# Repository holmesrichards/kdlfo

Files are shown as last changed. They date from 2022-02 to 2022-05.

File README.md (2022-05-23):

# Shape variable dual LFO

This is a dual LFO synth module in Kosmo format, based on a [Kassutronics design](https://kassu2000.blogspot.com/2015/10/variable-waveshape-lfo.html). There are three outputs for each LFO. Depending on the shape pot setting these provide ramp, asymmetric triangle, symmetric triangle, or sawtooth waveforms; sine or skewed "sine" waveforms; and narrow, square, or wide pulse waveforms respectively.

Version 1.0 corrects some first run problems. Version 1.0 PCB has not been tested.

## Current draw
32 mA +12 V, 32 mA -12 V

## Photos

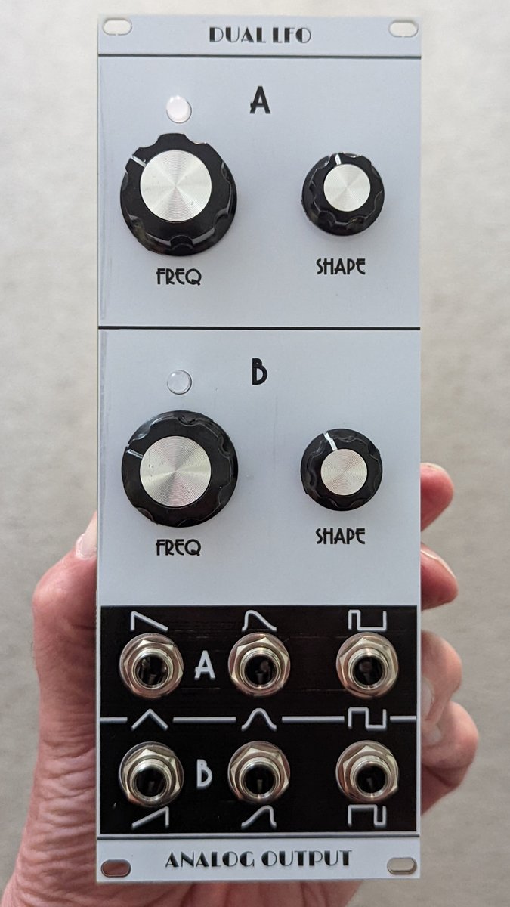
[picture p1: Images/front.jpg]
front


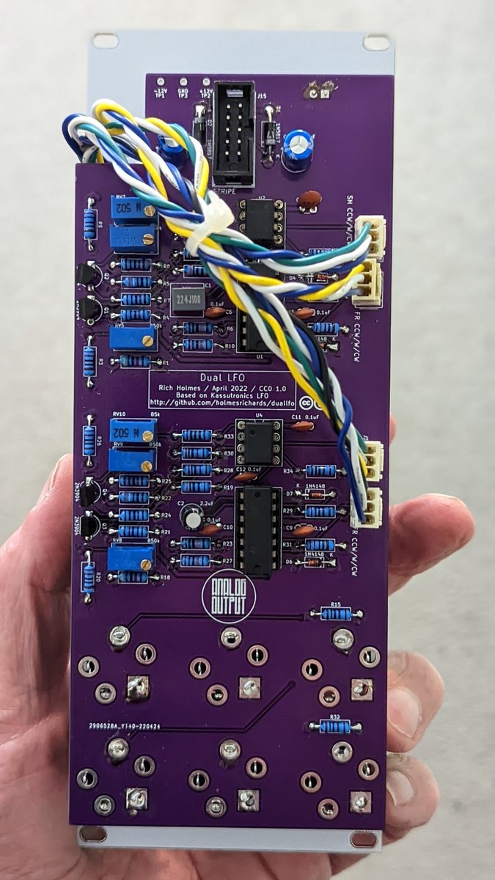
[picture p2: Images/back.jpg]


## Documentation

* [Schematic](Docs/kdlfo.pdf)
* PCB layout: [front](Docs/kdlfo_layout_front.pdf), [back](Docs/kdlfo_layout_back.pdf)
* [BOM](Docs/kdlfo_bom.md)
* [Build notes](Docs/build.md)
* [Blog post](https://analogoutputblog.wordpress.com/2022/05/11/kassutronics-dual-lfo/)

## GitHub repository

* [https://github.com/holmesrichards/duallfo](https://github.com/holmesrichards/kdlfo)

## Submodules

This repo uses submodules aoKicad and Kosmo_panel, which provide needed libaries for KiCad. To clone:

```
git clone git@github.com:holmesrichards/kdlfo.git
git submodule init
git submodule update
```

Alternatively do

```
git clone --recurse-submodules git@github.com:holmesrichards/kdlfo.git
```

Or if you download the repository as a zip file, you must also click on the "aoKicad" and "Kosmo\_panel" links on the GitHub page (they'll have "@ something" after them) and download them as separate zip files which you can unzip into this repo's aoKicad and Kosmo\_panel directories.

If desired, copy the files from aoKicad and Kosmo\_panel to wherever you prefer (your KiCad user library directory, for instance, if you have one). Then in KiCad, go into Edit Symbols and add symbol libraries 

```
aoKicad/ao_symbols
Kosmo_panel/Kosmo
```
and go into Edit Footprints and add footprint libraries 
```
aoKicad/ao_tht
Kosmo_panel/Kosmo_panel.
```

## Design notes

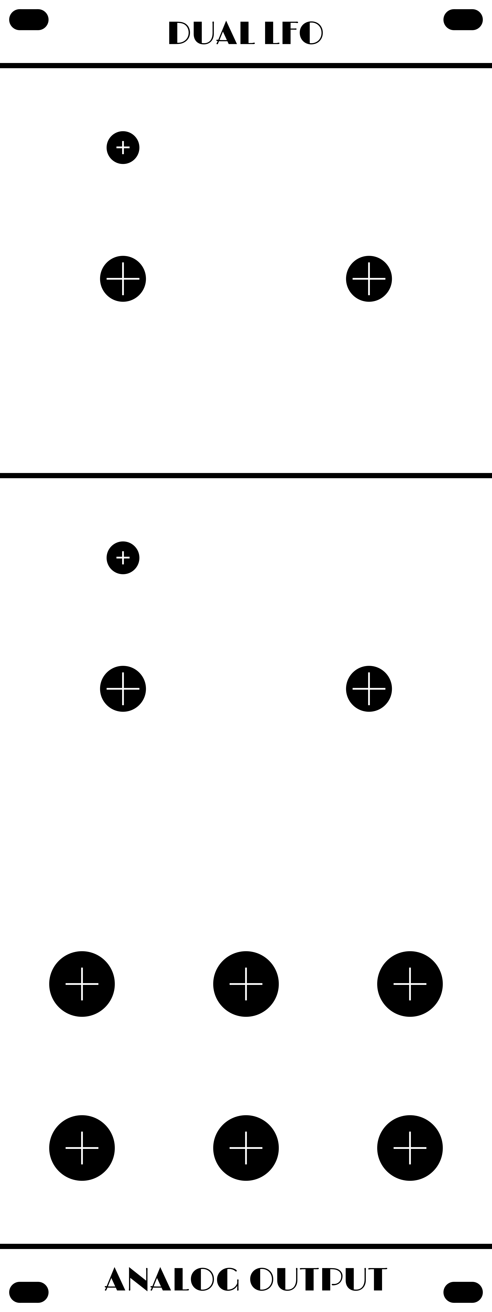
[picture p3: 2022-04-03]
Images/kdlfo_panel_holes.png

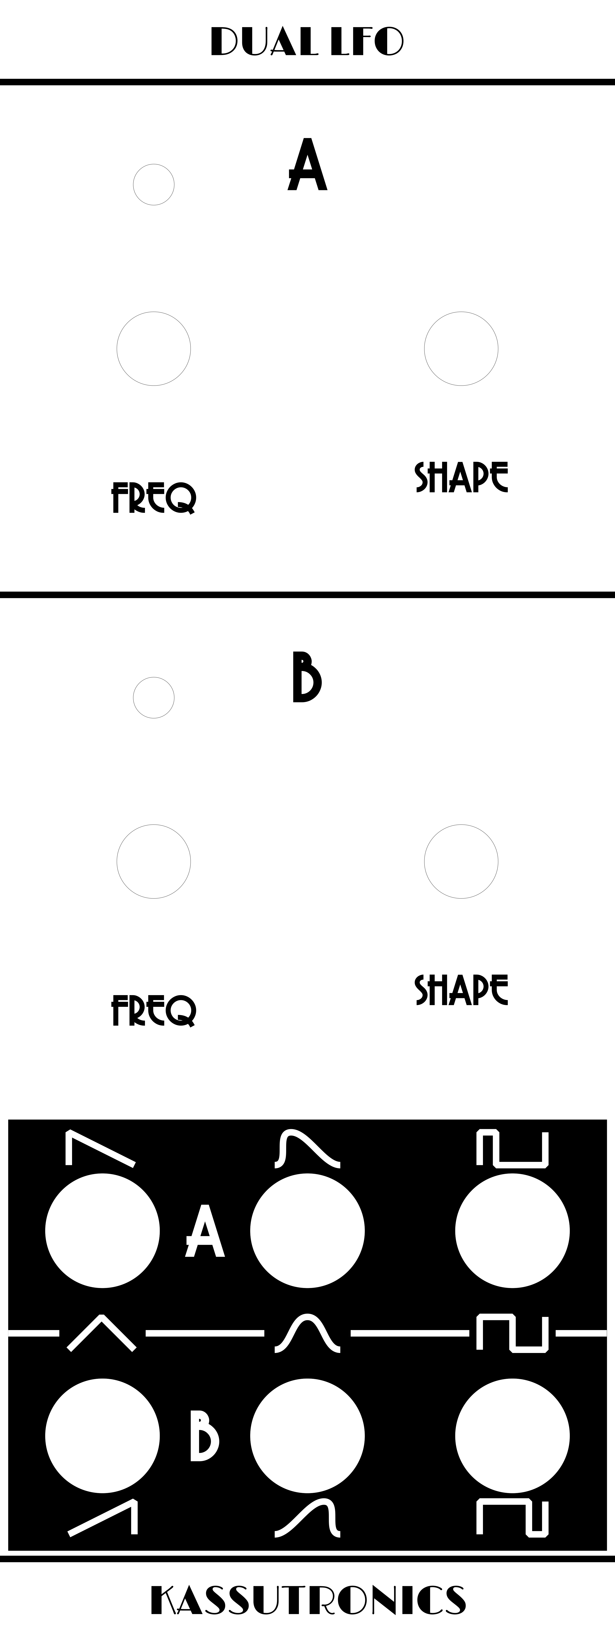
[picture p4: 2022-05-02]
Images/kdlfo_panel_art.png

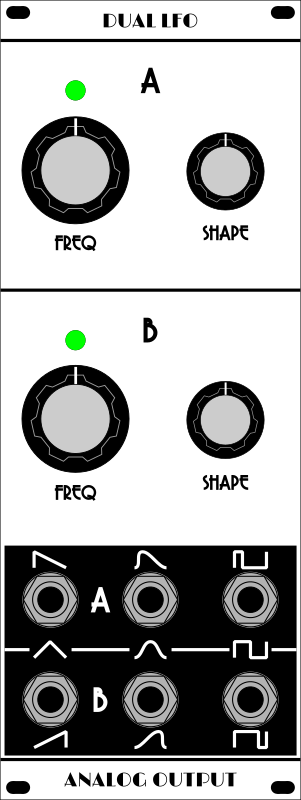
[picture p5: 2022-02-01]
Images/kdlfo_panel.png

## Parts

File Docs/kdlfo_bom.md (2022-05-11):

# kdlfo.kicad_sch BOM

Wed 11 May 2022 11:20:59 AM EDT

Generated from schematic by Eeschema 6.0.5-a6ca702e91~116~ubuntu20.04.1

**Component Count:** 87

| Refs | Qty | Component | Description | Vendor | SKU |
| ----- | --- | ---- | --- | ---- | ---- |
| C1 | 1 | 220n | Polyester capacitor | Tayda | A-984 |
| C2 | 1 | 2.2uF | Electrolytic capacitor, pitch 2.0 mm | Tayda | A-4532 |
| C3, C4 | 2 | 10uF | Electrolytic capacitor, pitch 2.5 mm | Tayda | A-4349 |
| C5, C6, C7, C8, C9, C10, C11, C12 | 8 | 0.1uF | Ceramic capacitor, pitch 2.5 mm | Tayda | A-553 |
| D1, D2 | 2 | 1N5817 | Schottky diode | Tayda | A-159 |
| D3, D4, D6, D7 | 4 | 1N4148 | 100V 0.15A standard switching diode, DO-35 | Tayda | A-157 |
| D5, D8 | 2 | LED_Dual_2pin | Dual LED, bidirectional | Tayda | A-1050 |
| J1, J2, J3, J4 | 4 | 3_pin_Molex_header | KK254 Molex header | Tayda | A-805 |
| J5, J6, J7, J8, J9, J10 | 6 | AudioJack2 | 1/4" phone jack, vertical | Tayda | A-1121 |
| J11, J12, J13, J14 | 4 | 3_pin_Molex_connector | KK254 Molex connector | Tayda | A-827 |
| J15 | 1 | Synth_power_2x5 | Pin header 2.54 mm 2x5 | Tayda | A-2939 |
| Q1, Q2, Q3, Q4 | 4 | 2N3904 | Small Signal NPN Transistor, TO-92 | Tayda | A-111 |
| R1, R18 | 2 | 47k | Resistor | Tayda |  |
| R2, R19 | 2 | 300R | Resistor | Tayda |  |
| R3, R9, R14, R20, R26, R31 | 6 | 2.2k | Resistor | Tayda |  |
| R4, R7, R21, R24 | 4 | 10k | Resistor | Tayda |  |
| R5, R22 | 2 | 390R | Resistor | Tayda |  |
| R6, R23 | 2 | 100k | Resistor | Tayda |  |
| R8, R25 | 2 | 18k | Resistor | Tayda |  |
| R10, R27 | 2 | 220k | Resistor | Tayda |  |
| R11, R13, R28, R30 | 4 | 20k | Resistor | Tayda |  |
| R12, R29 | 2 | 2.7k | Resistor | Tayda |  |
| R15, R32 | 2 | 1k | Resistor | Tayda |  |
| R16, R33 | 2 | 2k | Resistor | Tayda |  |
| R17, R34 | 2 | RL | Resistor | Tayda |  |
| R35, R36 | 2 | 200R | Resistor | Tayda |  |
| RV1, RV2, RV3, RV4 | 4 | B100k | Potentiometer | Tayda | A-1984 |
| RV5, RV6, RV8, RV9 | 4 | B50k | Trim-potentiometer | Tayda | A-598 |
| RV7, RV10 | 2 | B5k | Trim-potentiometer | Tayda | A-597 |
| U1, U3 | 2 | TL074 | Quad Low-Noise JFET-Input Operational Amplifiers, DIP-14/SOIC-14 | Tayda | A-1138 |
| U2, U4 | 2 | TL072 | Dual operational amplifier, DIP-8 | Tayda | A-037 |
| | 2 | | 8 pin DIP socket | Tayda | A-001 |
| | 2 | | 14 pin DIP socket | Tayda | A-004 |
| | 4 | | knobs | | |

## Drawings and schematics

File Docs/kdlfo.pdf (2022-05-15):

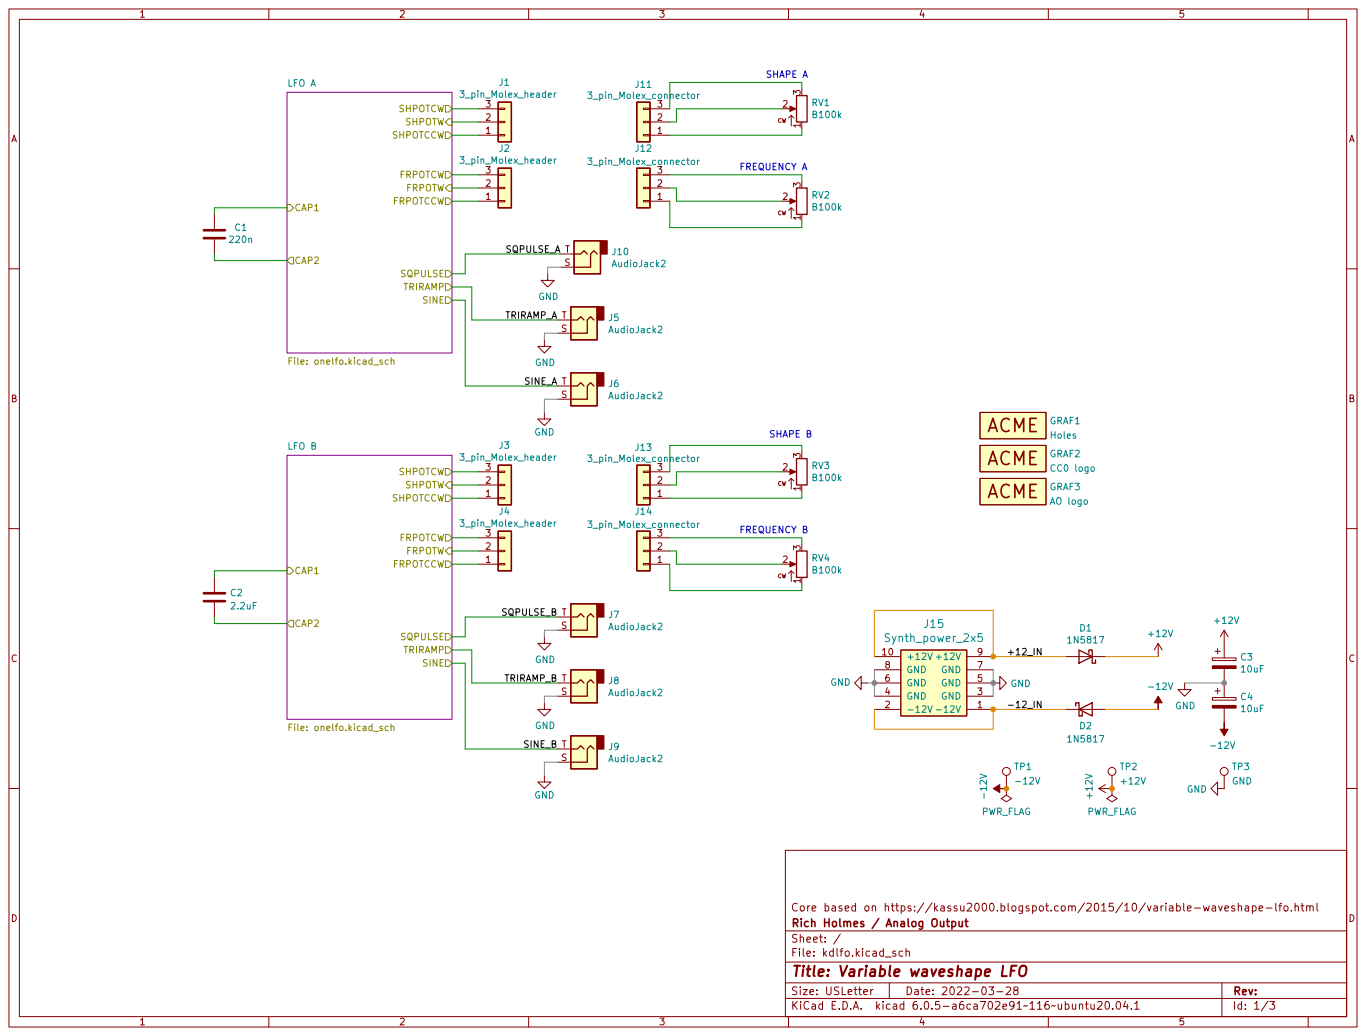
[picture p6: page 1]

Core based on https://kassu2000.blogspot.com/2015/10/variable-waveshape-lfo.html
File: kdlfo.kicad_sch Sheet: / Rich Holmes / Analog Output

Id: 1/3 Title: Variable waveshape LFO

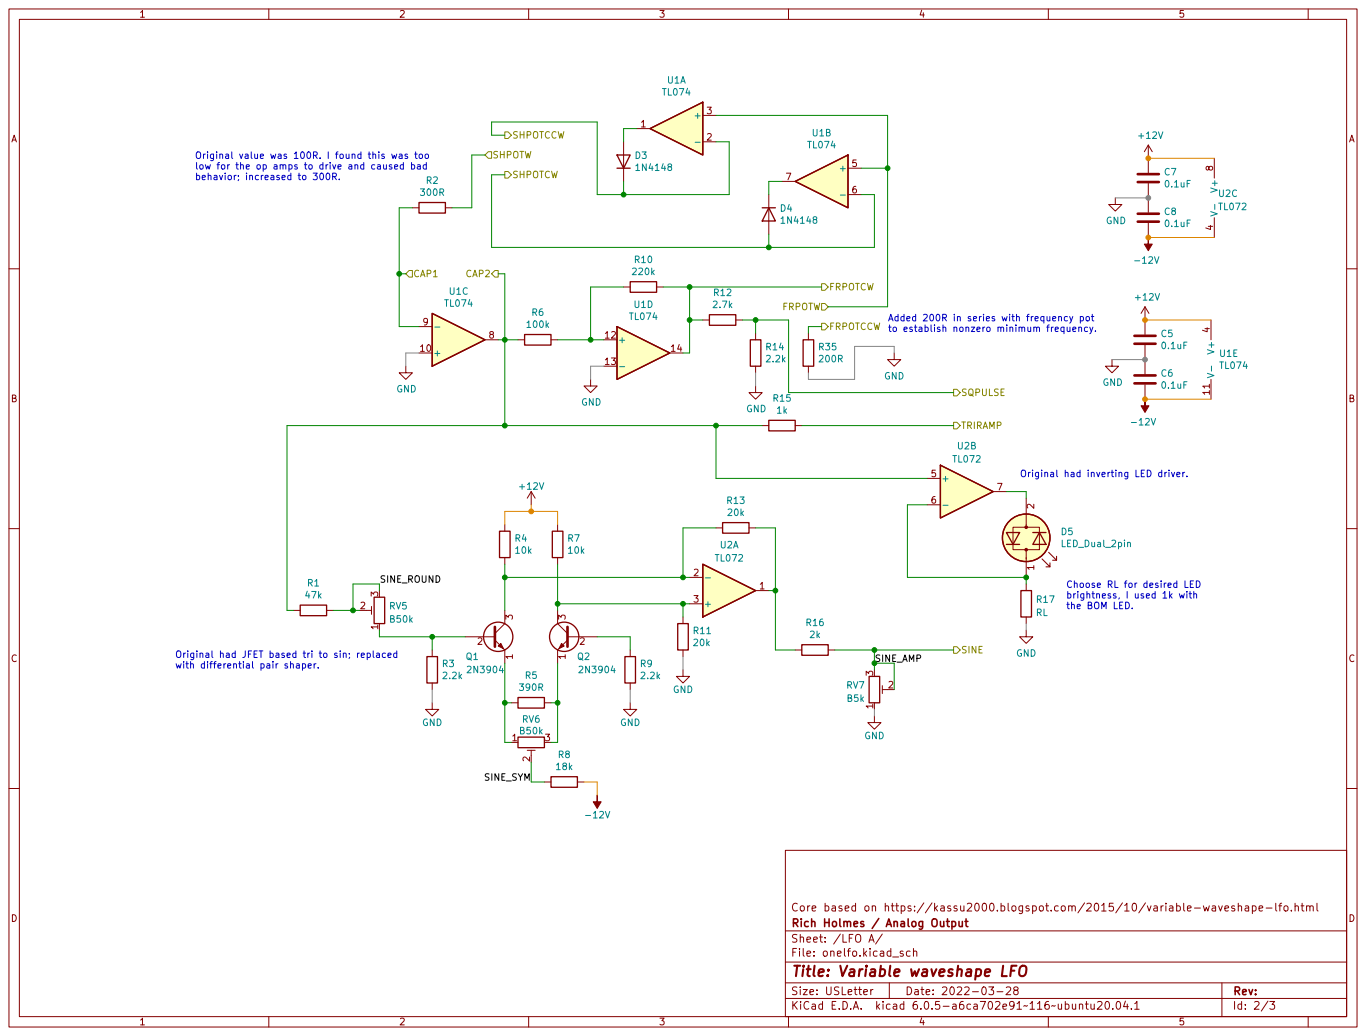
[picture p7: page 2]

Original value was 100R. I found this was too
low for the op amps to drive and caused bad

to establish nonzero minimum frequency.

Original had inverting LED driver. Choose RL for desired LED

Core based on https://kassu2000.blogspot.com/2015/10/variable-waveshape-lfo.html R1

the BOM LED. Original had JFET based tri to sin; replaced

with differential pair shaper.

File: onelfo.kicad_sch Sheet: /LFO A/ Rich Holmes / Analog Output

Id: 2/3 Title: Variable waveshape LFO

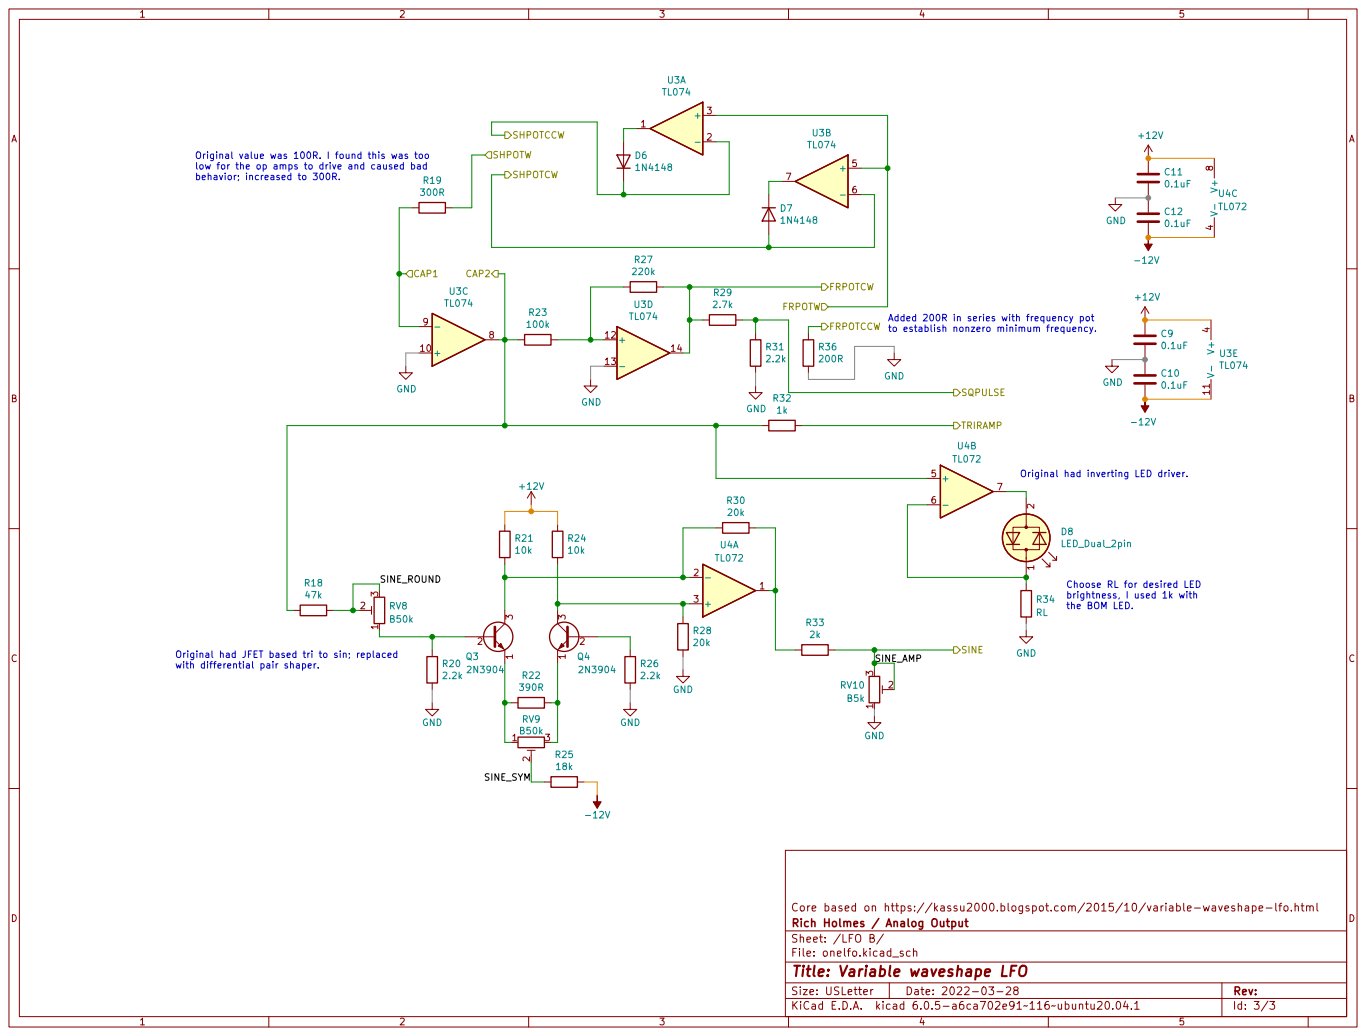
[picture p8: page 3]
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

to establish nonzero minimum frequency.

Original had inverting LED driver. Choose RL for desired LED

Core based on https://kassu2000.blogspot.com/2015/10/variable-waveshape-lfo.html R18

the BOM LED. Original had JFET based tri to sin; replaced

with differential pair shaper.

File: onelfo.kicad_sch Sheet: /LFO B/ Rich Holmes / Analog Output

Id: 3/3 Title: Variable waveshape LFO

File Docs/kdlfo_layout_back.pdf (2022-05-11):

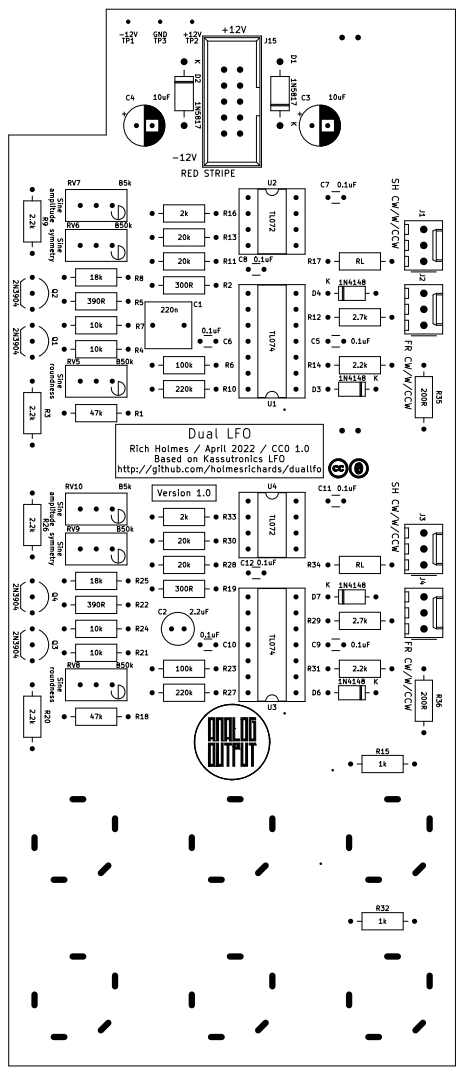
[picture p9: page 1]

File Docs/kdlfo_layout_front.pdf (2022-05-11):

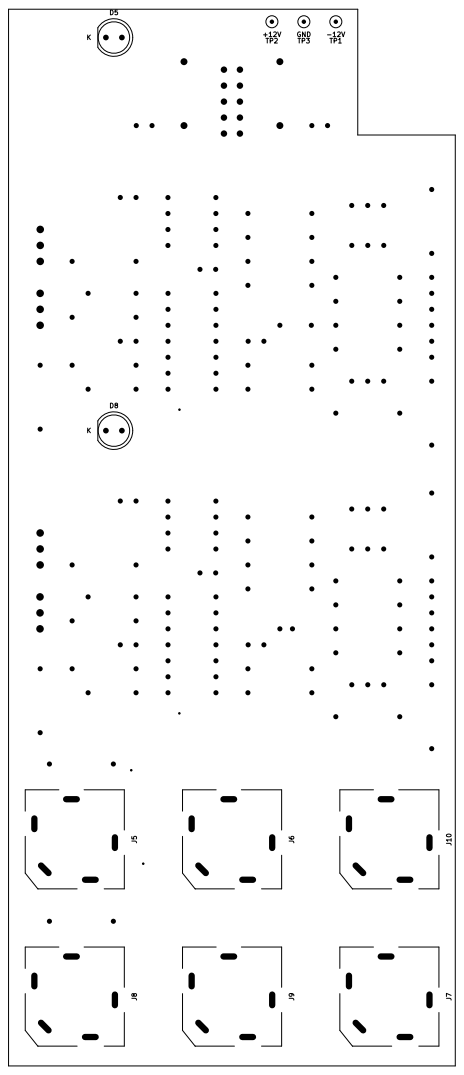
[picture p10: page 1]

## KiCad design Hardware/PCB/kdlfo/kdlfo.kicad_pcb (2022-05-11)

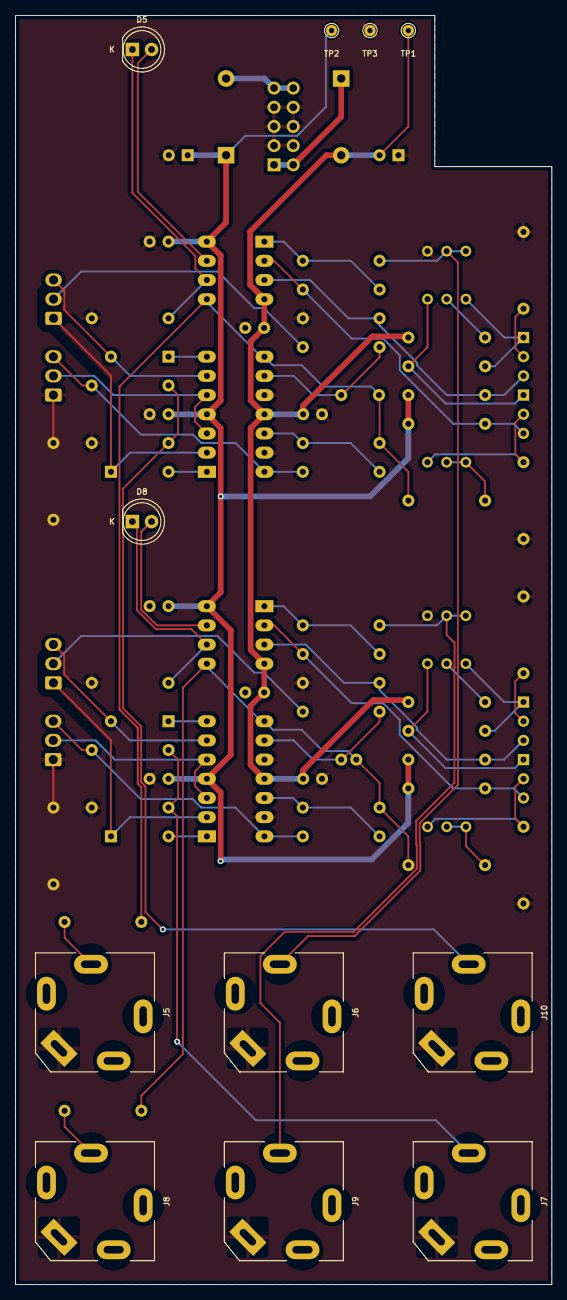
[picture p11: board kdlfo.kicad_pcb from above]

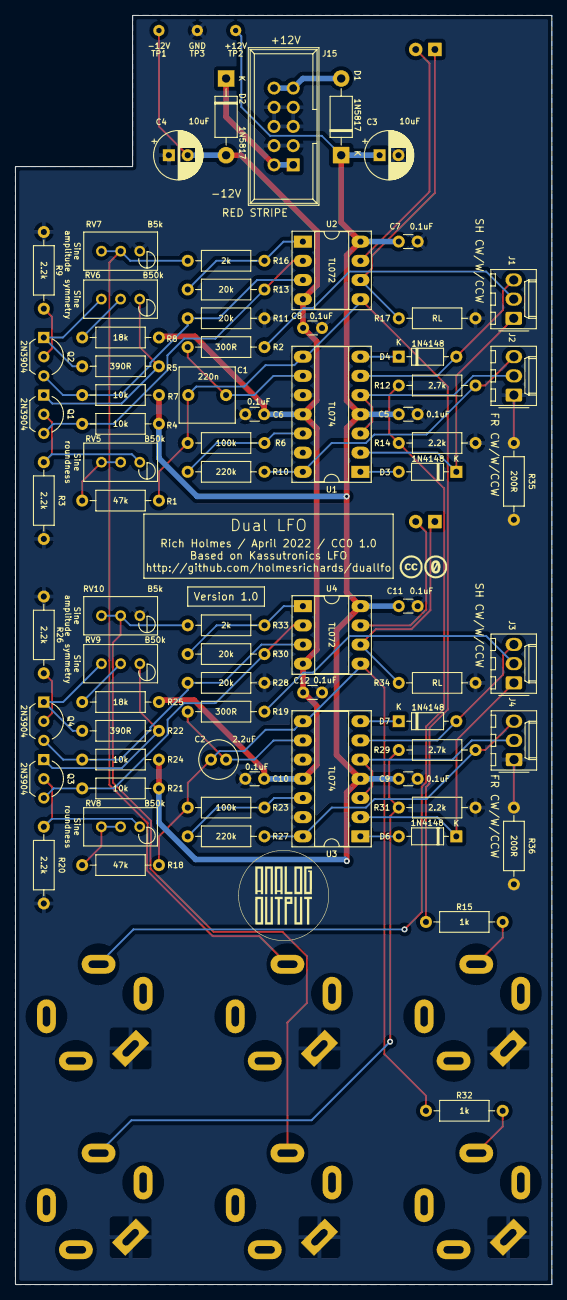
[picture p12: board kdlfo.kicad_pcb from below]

Board: 2 copper layers, 71.0 x 168.0 mm, 87 parts (75 on the bottom side), 55 nets.

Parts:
C1: 220n; C_Rect_L7.2mm_W7.2mm_P5.00mm_FKS2_FKP2_MKS2_MKP2
C2: 2.2uF; C_Radial_D5.0mm_H11.0mm_P2.00mm
C3, C4: 10uF; CP_Radial_D6.3mm_P2.50mm
C5, C6, C7, C8, C9, C10, C11, C12: 0.1uF; C_Disc_D3.0mm_W1.6mm_P2.50mm
D1, D2: 1N5817; D_DO-41_SOD81_P10.16mm_Horizontal
D3, D4, D6, D7: 1N4148; D_DO-35_SOD27_P7.62mm_Horizontal
D5, D8: LED_Dual_2pin; LED_D5.0mm
GRAF1: Holes; kdlfo_panel_holes
GRAF2: CC0 logo; CC0_logo
GRAF3: AO logo; analogoutput_12mm
J1, J2, J3, J4: 3_pin_Molex_header; Molex_KK-254_AE-6410-03A_1x03_P2.54mm_Vertical
J5, J6, J7, J8, J9, J10: AudioJack2; Jack_6.35mm_PJ_629HAN_slots
J15: Synth_power_2x5; Power_Header
Q1, Q2, Q3, Q4: 2N3904; TO-92_Inline_Wide
R1, R18: 47k; R_Axial_DIN0207_L6.3mm_D2.5mm_P10.16mm_Horizontal
R2, R19: 300R; R_Axial_DIN0207_L6.3mm_D2.5mm_P10.16mm_Horizontal
R3, R9, R14, R20, R26, R31: 2.2k; R_Axial_DIN0207_L6.3mm_D2.5mm_P10.16mm_Horizontal
R4, R7, R21, R24: 10k; R_Axial_DIN0207_L6.3mm_D2.5mm_P10.16mm_Horizontal
R5, R22: 390R; R_Axial_DIN0207_L6.3mm_D2.5mm_P10.16mm_Horizontal
R6, R23: 100k; R_Axial_DIN0207_L6.3mm_D2.5mm_P10.16mm_Horizontal
R8, R25: 18k; R_Axial_DIN0207_L6.3mm_D2.5mm_P10.16mm_Horizontal
R10, R27: 220k; R_Axial_DIN0207_L6.3mm_D2.5mm_P10.16mm_Horizontal
R11, R13, R28, R30: 20k; R_Axial_DIN0207_L6.3mm_D2.5mm_P10.16mm_Horizontal
R12, R29: 2.7k; R_Axial_DIN0207_L6.3mm_D2.5mm_P10.16mm_Horizontal
R15, R32: 1k; R_Axial_DIN0207_L6.3mm_D2.5mm_P10.16mm_Horizontal
R16, R33: 2k; R_Axial_DIN0207_L6.3mm_D2.5mm_P10.16mm_Horizontal
R17, R34: RL; R_Axial_DIN0207_L6.3mm_D2.5mm_P10.16mm_Horizontal
R35, R36: 200R; R_Axial_DIN0207_L6.3mm_D2.5mm_P10.16mm_Horizontal
RV5, RV6, RV8, RV9: B50k; Potentiometer_Bourns_3296W_Vertical_standard
RV7, RV10: B5k; Potentiometer_Bourns_3296W_Vertical_standard
TP1: -12V; TestPoint_THTPad_D1.5mm_Drill0.7mm
TP2: +12V; TestPoint_THTPad_D1.5mm_Drill0.7mm
TP3: GND; TestPoint_THTPad_D1.5mm_Drill0.7mm
U1, U3: TL074; DIP-14_W7.62mm_Socket_LongPads
U2, U4: TL072; DIP-8_W7.62mm_Socket_LongPads

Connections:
+12V: C3.1, C5.1, C7.1, C9.1, C11.1, D1.1 (K), R4.1, R7.1, R21.1, R24.1, TP2.1, U1.4 (V+), U2.8 (V+), U3.4 (V+), U4.8 (V+)
-12V: C4.2, C6.2, C8.2, C10.2, C12.2, D2.2 (A), R8.1, R25.1, TP1.1, U1.11 (V-), U2.4 (V-), U3.11 (V-), U4.4 (V-)
/+12_IN: D1.2 (A), J15.9 (+12V), J15.10 (+12V)
/-12_IN: D2.1 (K), J15.1 (-12V), J15.2 (-12V)
/LFO A/CAP1: C1.1, R2.2, U1.9 (-)
/LFO A/CAP2: C1.2, R1.2, R6.2, R15.2, U1.8, U2.5 (+)
/LFO A/FRPOTCCW: J2.1, R35.1
/LFO A/FRPOTCW: J2.3, R10.1, R12.2, U1.14
/LFO A/FRPOTW: J2.2, U1.3 (+), U1.5 (+)
/LFO A/SHPOTCCW: D3.1 (K), J1.1, U1.2 (-)
/LFO A/SHPOTCW: D4.2 (A), J1.3, U1.6 (-)
/LFO A/SHPOTW: J1.2, R2.1
/LFO A/SINE_ROUND: R1.1, RV5.2, RV5.3
/LFO A/SINE_SYM: R8.2, RV6.2
/LFO B/CAP1: C2.1, R19.2, U3.9 (-)
/LFO B/CAP2: C2.2, R18.2, R23.2, R32.2, U3.8, U4.5 (+)
/LFO B/FRPOTCCW: J4.1, R36.1
/LFO B/FRPOTCW: J4.3, R27.1, R29.2, U3.14
/LFO B/FRPOTW: J4.2, U3.3 (+), U3.5 (+)
/LFO B/SHPOTCCW: D6.1 (K), J3.1, U3.2 (-)
/LFO B/SHPOTCW: D7.2 (A), J3.3, U3.6 (-)
/LFO B/SHPOTW: J3.2, R19.1
/LFO B/SINE_ROUND: R18.1, RV8.2, RV8.3
/LFO B/SINE_SYM: R25.2, RV9.2
/SINE_A: J6.T, R16.1, RV7.2, RV7.3
/SINE_B: J9.T, R33.1, RV10.2, RV10.3
/SQPULSE_A: J10.T, R12.1, R14.1
/SQPULSE_B: J7.T, R29.1, R31.1
/TRIRAMP_A: J5.T, R15.1
/TRIRAMP_B: J8.T, R32.1
GND: C3.2, C4.1, C5.2, C6.1, C7.2, C8.1, C9.2, C10.1, C11.2, C12.1, J5.S, J6.S, J7.S, J8.S, J9.S, J10.S, J15.3 (GND), J15.4 (GND), J15.5 (GND), J15.6 (GND), J15.7 (GND), J15.8 (GND), R3.2, R9.2, R11.2, R14.2, R17.2, R20.2, R26.2, R28.2, R31.2, R34.2, R35.2, R36.2, RV7.1, RV10.1, TP3.1, U1.10 (+), U1.13 (-), U3.10 (+), U3.13 (-)
unnamed: D3.2 (A), U1.1
unnamed: D4.1 (K), U1.7
unnamed: D5.1 (KA), R17.1, U2.6 (-)
unnamed: D5.2 (AK), U2.7
unnamed: D6.2 (A), U3.1
unnamed: D7.1 (K), U3.7
unnamed: D8.1 (KA), R34.1, U4.6 (-)
unnamed: D8.2 (AK), U4.7
unnamed: Q1.1 (E), R5.2, RV6.1
unnamed: Q1.2 (B), R3.1, RV5.1
unnamed: Q1.3 (C), R4.2, R13.2, U2.2 (-)
unnamed: Q2.1 (E), R5.1, RV6.3
unnamed: Q2.2 (B), R9.1
unnamed: Q2.3 (C), R7.2, R11.1, U2.3 (+)
unnamed: Q3.1 (E), R22.2, RV9.1
unnamed: Q3.2 (B), R20.1, RV8.1
unnamed: Q3.3 (C), R21.2, R30.2, U4.2 (-)
unnamed: Q4.1 (E), R22.1, RV9.3
unnamed: Q4.2 (B), R26.1
unnamed: Q4.3 (C), R24.2, R28.1, U4.3 (+)
unnamed: R6.1, R10.2, U1.12 (+)
unnamed: R13.1, R16.2, U2.1
unnamed: R23.1, R27.2, U3.12 (+)
unnamed: R30.1, R33.2, U4.1

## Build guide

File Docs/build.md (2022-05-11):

# Dual LFO build notes

## ERRATA

OK, pay attention, this is going to be messy...

On the first run PCBs (no version # shown):

* The silkscreen labels for the Molex connector pins are backwards, CW should be CCW and vice versa. HOWEVER,
* The shape pot Molex connector pins are *connected* backwards, which means the silkscreen labels actually should be taken as correct for those pots. So connect CW (clockwise, viewed from front) pot pins to the "CCW" Molex pins for the frequency pots, and vice versa, but CW to CW and CCW to CCW for the shape pots. Got that?
* R2 and R19, shown as 100R, should be changed to 300R
* 200R resistors should be added between the counterclockwise pot pins and their wires on the shape pots:

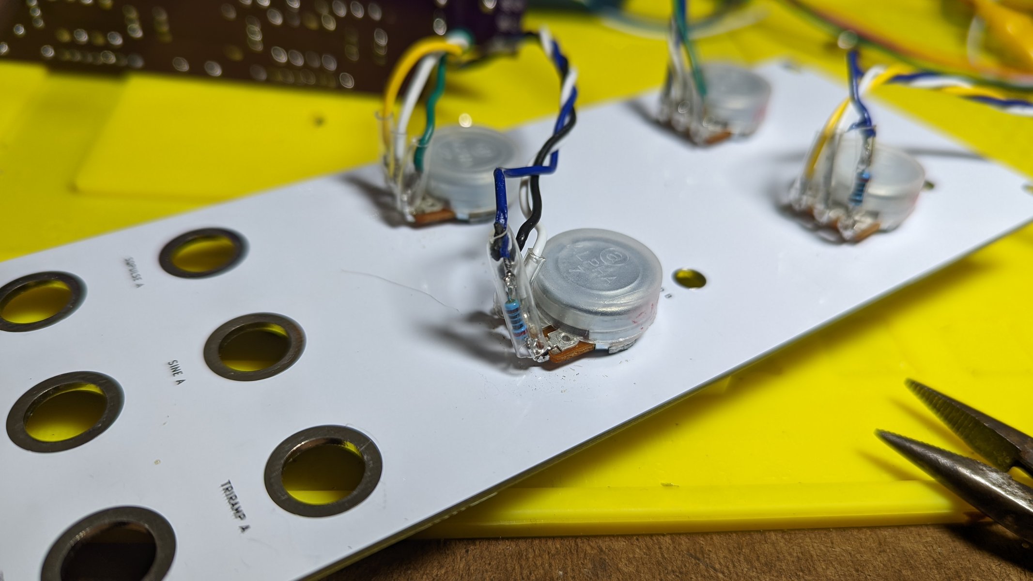
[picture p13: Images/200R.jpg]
200R


* Trim pots lack silkscreen labels, they are as shown:

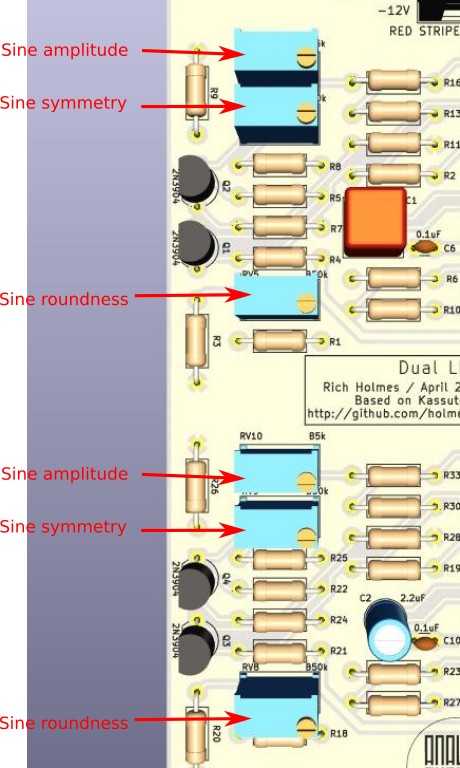
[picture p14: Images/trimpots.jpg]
trimpots


* "Analog Ouput" label on front panel should be "Kassutronics".

These have been corrected on v1.0 (version # shown on silkscreen) and later boards.

## Build

It's a straightforward build aside from the errata. Do the usual.

Adjust sine roundness trim pots to get as close to a sine as possible. Adjust sine symmetry trim pots to correct for differences between top and bottom of waveform shapes. Finally adjust sine amplitude trim pots for ±5 V.

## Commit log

2021-11-25 Initial version
    [kdlfo.kicad_pcb, kdlfo.kicad_sch, kdlfo.sch]
2021-11-25 Replace sine shaper, add divider on pulse output
    [kdlfo.kicad_sch, kdlfo.sch]
2022-02-01 Better .gitignore; rm extraneous footprint library; misc revisions
    [kdlfo.kicad_pcb, kdlfo.kicad_sch]
2022-03-28 Reorg schematic, redo layout
    [kdlfo.kicad_pcb, kdlfo.kicad_sch, onelfo.kicad_sch]
2022-03-28 Reorg schematic, redo layout some more
    [kdlfo.kicad_pcb, kdlfo.kicad_sch, onelfo.kicad_sch]
2022-04-03 Fix LED
    [kdlfo.kicad_pcb, kdlfo.kicad_sch, onelfo.kicad_sch]
2022-05-02 Final pre fab tweaks, Gerbers
    [kdlfo-CmtUser.gbr, kdlfo-CuBottom.gbl, kdlfo-CuTop.gtl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]
2022-05-02 Slotted jack footprints you idiot
    [kdlfo.kicad_pcb, kdlfo.kicad_sch, onelfo.kicad_sch]
2022-05-02 Front panel label -> Kassutronics
    [kdlfo_panel.kicad_pcb]
2022-05-11 Fix silkscreen errors and omissions, change integ resistor, add shape resistor
    [kdlfo-CmtUser.gbr, kdlfo-CuBottom.gbl, kdlfo-CuTop.gtl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]
2022-05-11 V1.0 untested PCB note
2022-05-15 Schematic annotations
    [onelfo.kicad_sch]
2022-05-23 Current draw

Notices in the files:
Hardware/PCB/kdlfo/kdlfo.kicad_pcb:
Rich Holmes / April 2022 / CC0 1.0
